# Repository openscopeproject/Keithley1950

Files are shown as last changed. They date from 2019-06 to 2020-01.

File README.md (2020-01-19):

# Keithley 195A DMM Option 1950

Keithley Instruments 195A Digital Multimeter is a 5½ digit resolution 200 000
count instrument that was manufactured in the 80's, possibly early 90's. It was
available in two configurations: base model that only had DC Volts and Ohms
measurements and model with 1950 option, which added DC/AC Amps and AC TRMS
Volts measurements.

Keithley DMM line has long replaced 195/196/199 series with newer models but
these still show up on Ebay and other outlets and they offer great performance
for reasonable prices. Unfortunately most of the 195A models available online
are the ones without 1950 Option.

This project aims to recreate the 1950 Option PCB and circuitry using modern
components.

In the process some upgrades and some compromises were made. For example this
version of 1950 option board is based on AD8436 trms chip that along with newer
opamps provides higher bandwidth and better overall specs than much older AD536
of the original. On the other hand cheaper shunt resistors are used (because
of their availability) with worse drift and tempco characteristics.

**High voltage** operation using the new board is also **NOT** recommended or
tested.

---

## BOM

See [bom](https://openscopeproject.org/InteractiveHtmlBomDemo/html/Keithley1950.html)
for this board generated by
[InteractiveHtmlBom](https://github.com/openscopeproject/InteractiveHtmlBom)
plugin for KiCad.

## Schematic



## 3D render



## Pictures

End result installed in the meter



Original board next to new version



Close up of rev A board with Genuine Bodge™ visible on the left



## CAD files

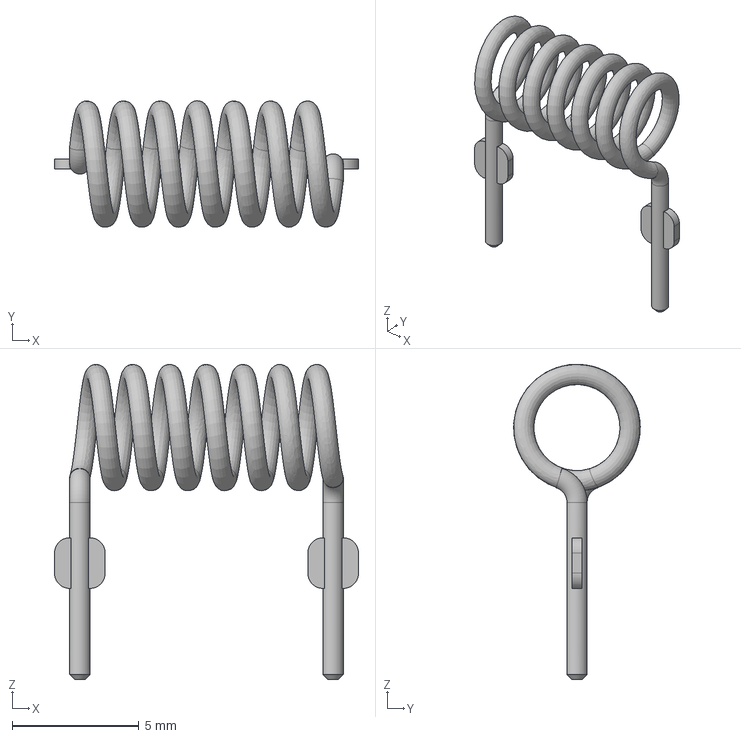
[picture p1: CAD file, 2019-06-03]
3dshapes/R_2512_With_10mm_axial_fp.step
12.0 x 5.00 x 12.4 mm

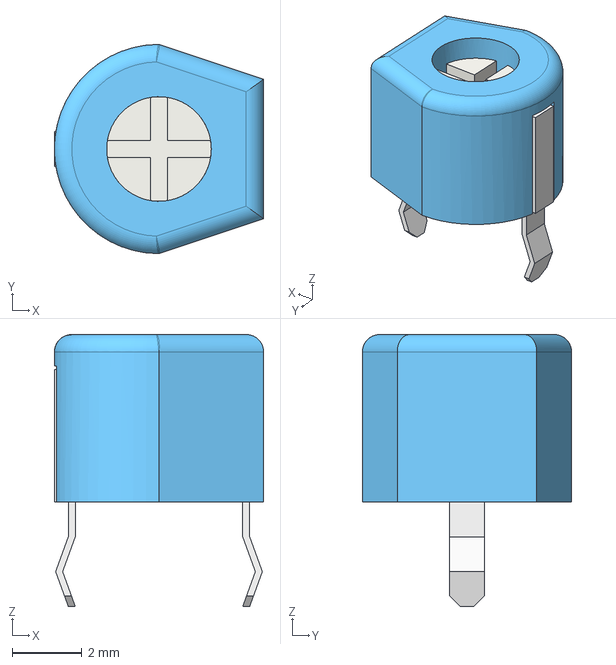
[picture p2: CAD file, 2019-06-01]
3dshapes/MURATA_TZ03.step
6.00 x 6.00 x 7.80 mm

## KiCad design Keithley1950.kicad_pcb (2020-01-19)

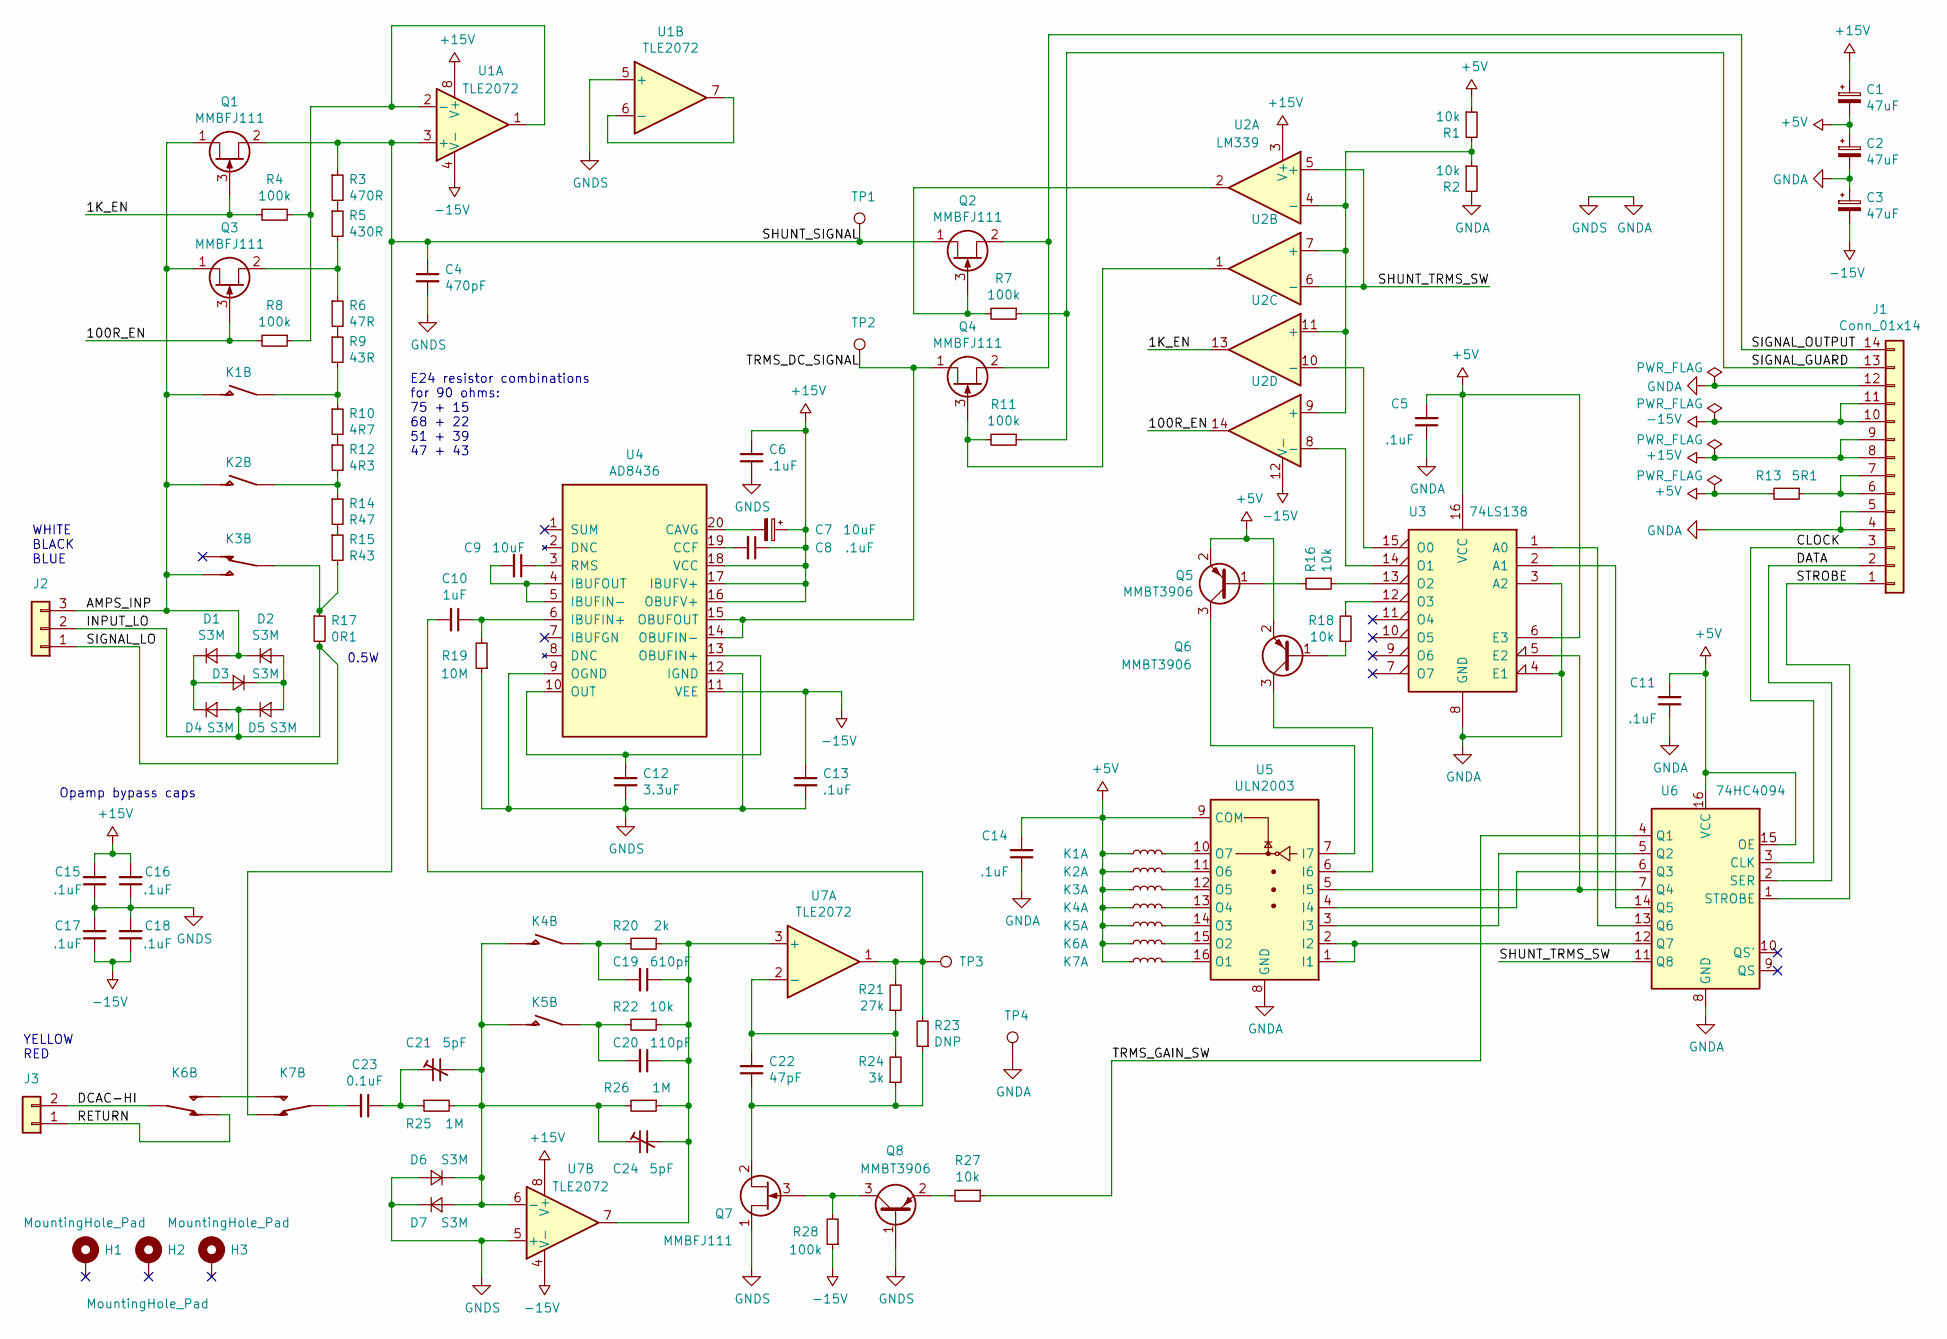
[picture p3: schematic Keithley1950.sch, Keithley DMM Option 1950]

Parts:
C1, C2, C3: 47uF; CP_Elec_6.3x5.9
C4: 470pF; C_0805_2012Metric
C5, C6, C8, C11, C13, C14, C15, C16, C17, C18: .1uF; C_0603_1608Metric
C7: 10uF; CP_EIA-3528-21_Kemet-B
C9: 10uF; C_0805_2012Metric
C10: 1uF; C_0805_2012Metric
C12: 3.3uF; C_0805_2012Metric
C19: 610pF; C_0805_2012Metric
C20: 110pF; C_0805_2012Metric
C21, C24: 5pF; MURATA_TZ03
C22: 47pF; C_0805_2012Metric
C23: 0.1uF; C_Rect_L18.0mm_W5.0mm_P15.00mm_FKS3_FKP3
D1, D2, D3, D4, D5, D6, D7: S3M; D_SMB
H1, H2, H3: MountingHole_Pad; MountingHole_3.2mm_M3_Pad_Via
J1: Conn_01x14; DIP-14_W7.62mm_Socket_LongPads
J2: Conn_01x03; TerminalBlock_Phoenix_PT-1,5-3-5.0-H_1x03_P5.00mm_Horizontal
J3: Conn_01x02; TerminalBlock_Phoenix_PT-1,5-2-5.0-H_1x02_P5.00mm_Horizontal
K1, K2, K4, K5: Relay_SP2P; Relay_SPST_StandexMeder_SIL_Form1A
K3, K6, K7: Relay_SP3P; Relay_SPDT_SANYOU_SRD_Series_Form_C
Q1, Q2, Q3, Q4, Q7: MMBFJ111; SOT-23
Q5, Q6, Q8: MMBT3906; SOT-23
R1, R2, R16, R18, R22, R27: 10k; R_0805_2012Metric
R3: 470R; R_0805_2012Metric
R4, R7, R8, R11, R28: 100k; R_0805_2012Metric
R5: 430R; R_0805_2012Metric
R6: 47R; R_0805_2012Metric
R9: 43R; R_0805_2012Metric
R10: 4R7; R_0805_2012Metric
R12: 4R3; R_0805_2012Metric
R13: 5R1; R_2512_6332Metric
R14: R47; R_2512_6332Metric
R15: R43; R_2512_6332Metric
R17: 0R1; R_2512_With_10mm_axial
R19: 10M; R_0805_2012Metric
R20: 2k; R_0805_2012Metric
R21: 27k; R_0805_2012Metric
R23: DNP; R_0805_2012Metric
R24: 3k; R_0805_2012Metric
R25, R26: 1M; R_0805_2012Metric
TP1, TP2, TP3: TestPoint; TestPoint_Pad_D2.5mm
TP4: TestPoint; TestPoint_THTPad_D1.5mm_Drill0.7mm
U1, U7: TLE2072; SOIC-8_3.9x4.9mm_P1.27mm
U2: LM339; SOIC-14_3.9x8.7mm_P1.27mm
U3: 74LS138; SOIC-16_3.9x9.9mm_P1.27mm
U4: AD8436; QSOP-20_3.9x8.7mm_P0.635mm
U5: ULN2003; SOIC-16_3.9x9.9mm_P1.27mm
U6: 74HC4094; SOIC-16_3.9x9.9mm_P1.27mm

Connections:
+5V: C1.2, C2.1, C5.2, C11.2, C14.2, K1.3, K2.3, K3.2, K4.3, K5.3, K6.2, K7.2, Q5.2 (E), Q6.2 (E), R1.1, R13.2, U3.6 (E3), U3.16 (VCC), U5.9 (COM), U6.15 (OE), U6.16 (VCC)
+15V: C1.1, C6.1, C7.1, C8.1, C15.2, C16.2, J1.8, J1.9, U1.8 (V+), U2.3 (V+), U4.16 (OBUFV+), U4.17 (IBUFV+), U4.18 (VCC), U7.8 (V+)
-15V: C3.2, C13.1, C17.1, C18.1, J1.10, J1.11, R28.1, U1.4 (V-), U2.12 (V-), U4.11 (VEE), U7.4 (V-)
/1K_EN: Q1.3 (G), R4.2, U2.13
/100R_EN: Q3.3 (G), R8.2, U2.14
/AMPS_INP: D1.2 (A), D2.1 (K), J2.3, K1.7, K2.7, K3.3, Q1.1 (D), Q3.1 (D)
/CLOCK: J1.3, U6.3 (CLK)
/DATA: J1.2, U6.2 (SER)
/DCAC-HI: J3.2, K6.1
/INPUT_LO: D4.2 (A), D5.1 (K), J2.1, J2.2, R17.2
/RETURN: J3.1, K6.4
/SHUNT_SIGNAL: C4.1, K7.4, Q1.2 (S), Q2.1 (D), R3.1, TP1.1, U1.3 (+)
/SHUNT_TRMS_SW: U2.5 (+), U2.6 (-), U6.11 (Q8)
/SIGNAL_GUARD: J1.13, R7.1, R11.1
/SIGNAL_OUTPUT: J1.14, Q2.2 (S), Q4.2 (S)
/STROBE: J1.1, U6.1 (STROBE)
/TRMS_DC_SIGNAL: Q4.1 (D), TP2.1, U4.14 (OBUFIN-), U4.15 (OBUFOUT)
/TRMS_GAIN_SW: R27.1, U6.4 (Q1)
GNDA: C2.2, C3.1, C4.2, C5.1, C6.2, C11.1, C12.2, C13.2, C14.1, C15.1, C16.1, C17.2, C18.2, D6.2 (A), D7.1 (K), J1.4, J1.5, J1.12, Q7.1 (D), Q8.1 (B), R2.2, R19.1, TP4.1, U1.5 (+), U3.3 (A2), U3.4 (E1), U3.8 (GND), U4.9 (OGND), U4.12 (IGND), U5.8 (GND), U6.8 (GND), U7.5 (+)
unnamed: C7.2, U4.20 (CAVG)
unnamed: C8.2, U4.19 (CCF)
unnamed: C9.1, U4.3 (RMS)
unnamed: C9.2, U4.4 (IBUFOUT), U4.5 (IBUFIN-)
unnamed: C10.1, R19.2, U4.6 (IBUFIN+)
unnamed: C10.2, R21.2, R23.2, TP3.1, U7.1
unnamed: C12.1, U4.10 (OUT), U4.13 (OBUFIN+)
unnamed: C19.1, C20.1, C24.2, R20.1, R22.1, R26.1, U7.3 (+), U7.7
unnamed: C19.2, K4.1, R20.2
unnamed: C20.2, K5.1, R22.2
unnamed: C21.1, C23.1, R25.1
unnamed: C21.2, C24.1, D6.1 (K), D7.2 (A), K4.7, K5.7, R25.2, R26.2, U7.6 (-)
unnamed: C22.1, Q7.2 (S), R23.1, R24.1
unnamed: C22.2, R21.1, R24.2, U7.2 (-)
unnamed: C23.2, K7.1
unnamed: D1.1 (K), D3.2 (A), D4.1 (K)
unnamed: D2.2 (A), D3.1 (K), D5.2 (A)
unnamed: J1.6, J1.7, R13.1
unnamed: K1.1, R9.2, R10.1
unnamed: K1.5, U5.10 (O7)
unnamed: K2.1, R12.2, R14.1
unnamed: K2.5, U5.11 (O6)
unnamed: K3.1, R15.2, R17.1
unnamed: K3.5, U5.12 (O5)
unnamed: K4.5, U5.13 (O4)
unnamed: K5.5, U5.14 (O3)
unnamed: K6.3, K7.3
unnamed: K6.5, U5.15 (O2)
unnamed: K7.5, U5.16 (O1)
unnamed: Q2.3 (G), R7.2, U2.2
unnamed: Q3.2 (S), R5.2, R6.1
unnamed: Q4.3 (G), R11.2, U2.1
unnamed: Q5.1 (B), R16.2
unnamed: Q5.3 (C), U5.7 (I7)
unnamed: Q6.1 (B), R18.1
unnamed: Q6.3 (C), U5.6 (I6)
unnamed: Q7.3 (G), Q8.3 (C), R28.2
unnamed: Q8.2 (E), R27.2
unnamed: R1.2, R2.1, U2.4 (-), U2.7 (+), U2.9 (+), U2.11 (+)
unnamed: R3.2, R5.1
unnamed: R4.1, R8.1, U1.1, U1.2 (-)
unnamed: R6.2, R9.1
unnamed: R10.2, R12.1
unnamed: R14.2, R15.1
unnamed: R16.1, U3.13 (O2)
unnamed: R18.2, U3.12 (O3)
unnamed: U1.6 (-), U1.7
unnamed: U2.8 (-), U3.14 (O1)
unnamed: U2.10 (-), U3.15 (O0)
unnamed: U3.1 (A0), U6.13 (Q6)
unnamed: U3.2 (A1), U6.14 (Q5)
unnamed: U3.5 (E2), U5.5 (I5), U6.7 (Q4)
unnamed: U5.1 (I1), U5.2 (I2), U6.12 (Q7)
unnamed: U5.3 (I3), U6.5 (Q2)
unnamed: U5.4 (I4), U6.6 (Q3)

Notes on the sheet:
WHITE BLACK BLUE
YELLOW RED
E24 resistor combinations for 90 ohms: 75 + 15 68 + 22 51 + 39 47 + 43
Opamp bypass caps
0.5W

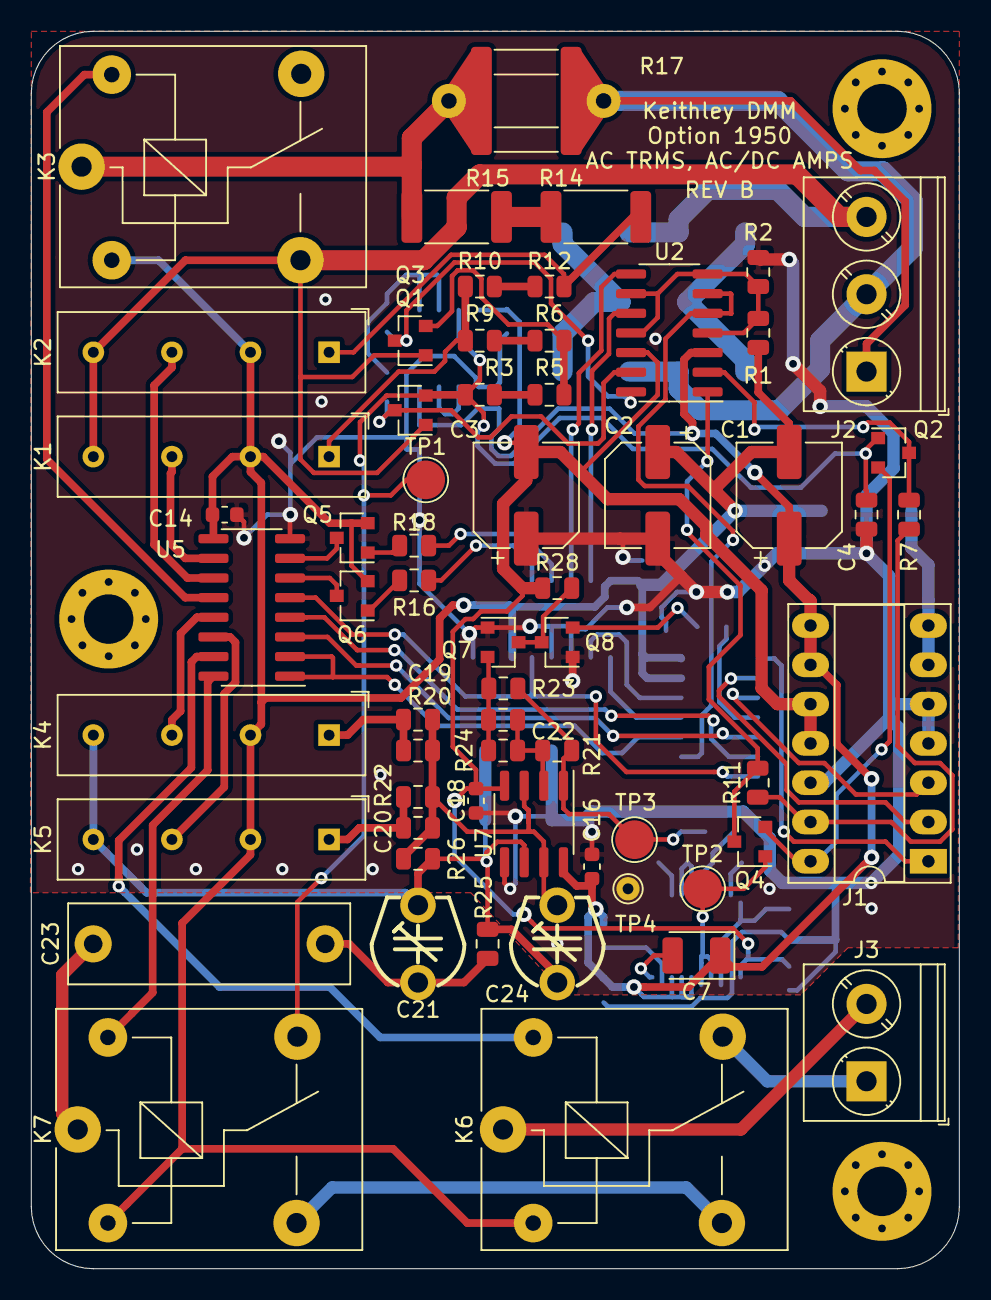
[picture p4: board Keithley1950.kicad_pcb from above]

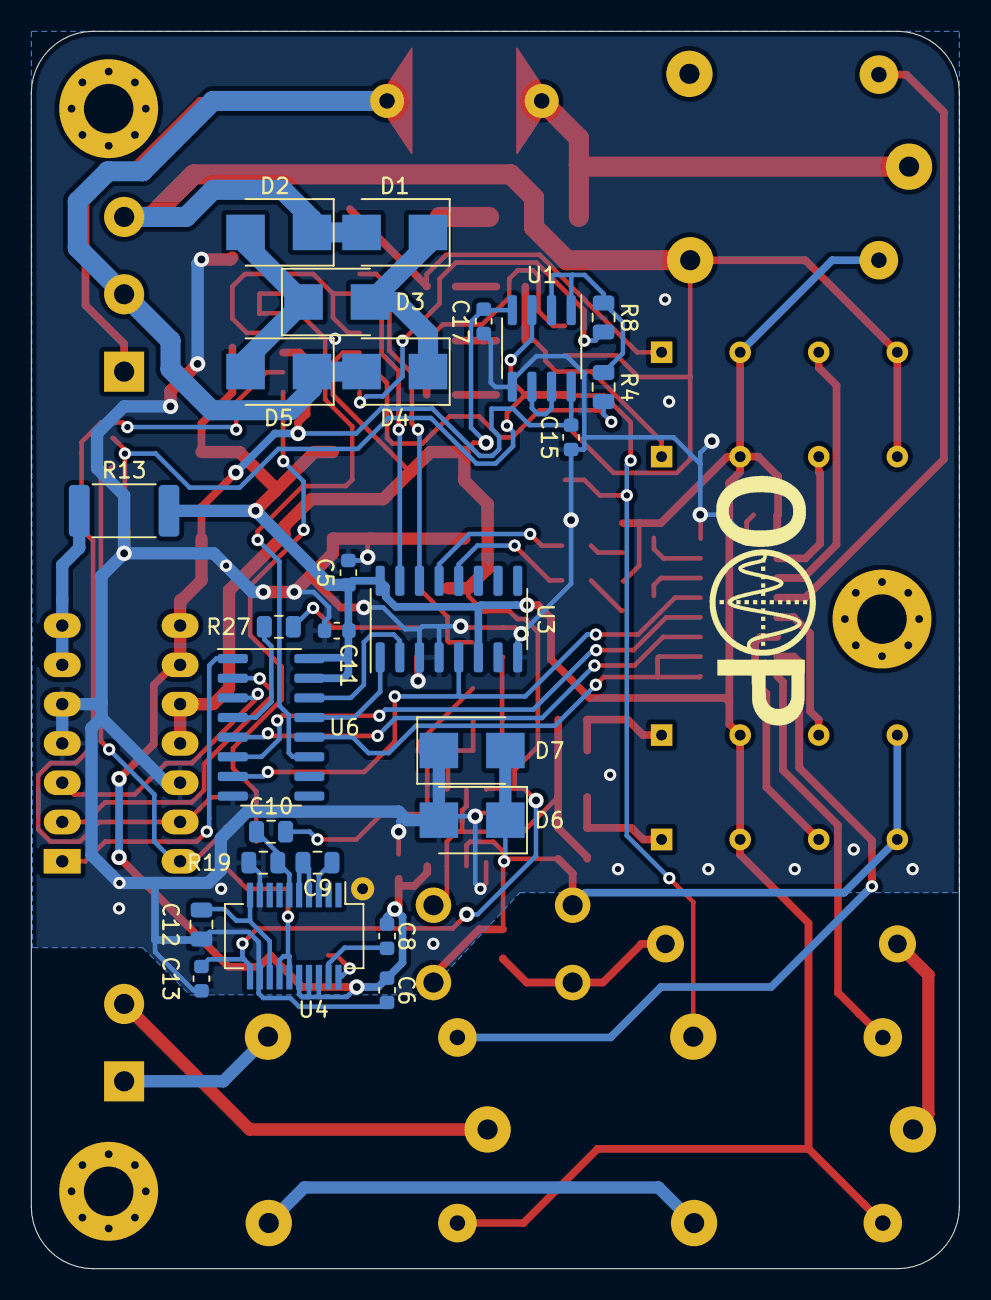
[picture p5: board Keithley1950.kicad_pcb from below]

Board: 2 copper layers, 60.0 x 80.0 mm, 92 parts (27 on the bottom side), 74 nets.

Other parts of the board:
LOGO***: LOGO; osp-logo

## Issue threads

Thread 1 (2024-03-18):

5pF Murata TZ03 Capacitor is obsolete

mrozy2006, 2024-03-18:
I noticed that the 5pF Murata TZ03 is no longer in production.
I would recommend finding an alternative and adjusting the PCB

Closed 2024-03-18.

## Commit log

2019-04-15 First schematic pass
    [Keithley1950.kicad_pcb, Keithley1950.sch]
2019-05-03 Schematic work
    [Keithley1950.sch]
2019-05-06 More schematic work, put some values in
    [Keithley1950.sch]
2019-05-30 Almost all components fully specified
    [Keithley1950.sch]
2019-05-30 Switched to AD8436, finished schematic
    [Keithley1950.sch]
2019-06-01 Switch to 2 serial resistors for shunts in schematic
    [Keithley1950.sch]
2019-06-01 Add TZ03 model, some tweaks
    [Keithley1950.sch, MURATA_TZ03.step]
2019-06-03 Add constantan spiral model
    [Keithley1950.kicad_pcb, Keithley1950.sch, R_2512_With_10mm_axial_fp.step]
2019-06-19 Initial placement on pcb
    [Keithley1950.kicad_pcb, Keithley1950.sch]
2019-06-23 Optimized placement
    [Keithley1950.kicad_pcb, Keithley1950.sch]
2019-06-23 More optimizations
    [Keithley1950.kicad_pcb, Keithley1950.sch]
2019-06-24 Manual routing done
    [Keithley1950.kicad_pcb]
2019-06-24 Clean up silkscreen, add logos
    [Keithley1950.kicad_pcb]
2019-06-24 Add metadata, generate bom
    [Keithley1950.kicad_pcb, Keithley1950.sch]
2019-06-24 Fix input sense track overlap
    [Keithley1950.kicad_pcb]
2019-07-04 Fixes, tweaks, tag rev A
    [Keithley1950-B_Cu.gbr, Keithley1950-B_Mask.gbr, Keithley1950-B_SilkS.gbr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]
2019-11-17 Revision B
    1. Clearance for high voltage lines
    2. 14 pin connector courtyard overlap
    3. 24K resistor is DNP
    4. Fix swapped inputs of U7B
    5. Change c7 to tantalum type Bx
    [Keithley1950.kicad_pcb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]
2020-01-19 Regenerate bom
    [Keithley1950.kicad_pcb]
2020-01-19 Replot gerbers
    [Keithley1950-B_Cu.gbr, Keithley1950-B_Mask.gbr, Keithley1950-B_SilkS.gbr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]
